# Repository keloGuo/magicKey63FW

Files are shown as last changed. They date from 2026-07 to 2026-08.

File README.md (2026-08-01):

# MagicKey63

<p align="right">
  English |
  <a href="README.zh-CN.md">中文</a>
</p>

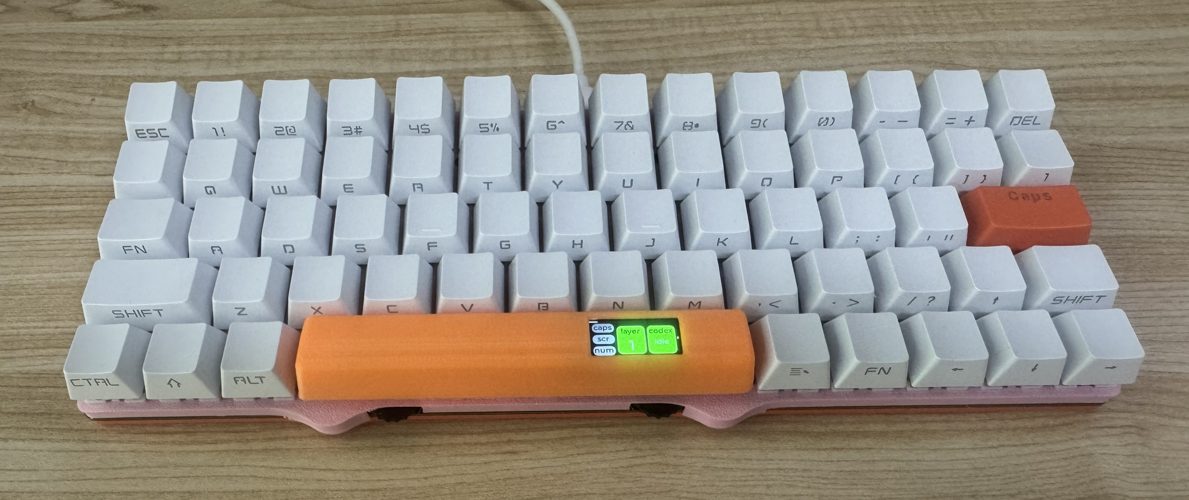
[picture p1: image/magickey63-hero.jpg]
MagicKey63 keyboard front view


MagicKey63 is an open-source RP2040 interactive hardware platform built into a compact mechanical keyboard. It works as a daily 63-key keyboard, but it is also designed for engineers, makers, and firmware hackers who want to modify and extend their desktop tools.

The project includes RP2040 firmware, USB HID/RNDIS, a browser-based web configuration UI, LittleFS storage, an LVGL onboard screen UI, WS2812 lighting, macro recording/playback, switch bounce diagnostics, hardware files, and mechanical design files.

### Features

- Compact 63-key layout with arrow keys and practical editing keys.
- RP2040 firmware with matrix scanning, USB HID, USB networking, and device-side HTTP APIs.
- Self-hosted web configuration page for keymap editing, macro management, resource upload, and version display.
- The web settings page can be updated independently without reflashing the full firmware.
- LVGL onboard UI with status, layer, lighting, network, and bootloader pages.
- Hidden dual clickable encoders for layer switching, volume, menu control, or custom workflows.
- Device-side macro recording, storage, and playback without host-side macro software.
- PIO/DMA-based key scanning and WS2812 driving to reduce real-time CPU load.
- Switch bounce diagnostics for validating switches, debounce behavior, and scan timing.
- Firmware, web UI, hardware files, and mechanical files are open-sourced under separate licenses.

### Build

Build from the repository root. A local Raspberry Pi Pico SDK checkout is required:

```sh
export PICO_SDK_PATH=/path/to/pico-sdk
cmake -S . -B build
cmake --build build
```

The generated UF2 is available at:

```text
build/firmware.uf2
```

For release and debug builds, use the project script:

```sh
tool/build_firmware.sh --release --incremental -j 8
tool/build_firmware.sh --release --clean -j 8
tool/build_firmware.sh --debug --incremental -j 8
```

Local checks:

```sh
tool/check_ci.sh
```

### Flash

When the device is connected to a Windows host through WSL2, use:

```sh
WINDOWS_DRIVE='E:\' TIMEOUT_SECONDS=120 ./tool/flash_uf2_wsl.sh
```

If the device IP has been changed, provide the matching bootloader URL:

```sh
BOOTLOADER_URL=http://172.23.63.1/api/rebootToUf2 ./tool/flash_uf2_wsl.sh
```

You can also enter UF2 mode manually and copy `build/firmware.uf2` to the `RPI-RP2` volume.

### Web Configuration

Default USB network address:

```text
http://10.63.27.1:80
```

The device can switch to alternate IP presets or a custom IP. Tool scripts accept `DEVICE_URL` and `BOOTLOADER_URL`:

```sh
DEVICE_URL=http://172.23.63.1:80 python3 tool/upload_html.py
BOOTLOADER_URL=http://172.23.63.1/api/rebootToUf2 ./tool/flash_uf2_wsl.sh
```

After editing `web/webServer/index.html`, `index.css`, or `main.js`, regenerate the tracked single-file page:

```sh
python3 tool/build_single_html.py
git diff --exit-code -- web/webServer/out/index.html
```

### License Notes

Different parts of this repository use different licenses. See `LICENSE` and `THIRD_PARTY_LICENSES.md`.

- Firmware, web UI, and development tools: GPL-2.0-only.
- Hardware electronics design files: CERN-OHL-S-2.0.
- Case and mechanical 3D files: CC-BY-SA-4.0.
- Mongoose is licensed as `GPL-2.0-only or commercial`. This firmware project uses the GPL-2.0-only option. Closed-source or non-GPL commercial redistribution requires separate Mongoose commercial licensing.
- LVGL, littlefs, cJSON, TinyUSB, and Pico SDK components keep their own license notices.

### VID/PID Status

The USB VID/PID has been updated to the Raspberry Pi provided assignment: `0x2E8A:0x113A`. The assignment source is documented in `firmware/usb/usb_descriptors.c`, and the firmware no longer uses TinyUSB demo IDs or a temporary development PID.

Before release, run:

```sh
tool/check_ci.sh --strict-release
```

## Repository Layout

- `firmware/`: RP2040 Pico SDK firmware source code and firmware-side third
  party libraries.
- `web/`: Web settings UI source files and generated single-file output.
- `tool/`: Development, upload, flashing, packaging, and Codex status sync
  scripts.
- `case_3d/`: Keyboard enclosure and mechanical structure 3D files.
- `hardware/`: Schematics and hardware manufacturing source/export files.
- `tool/dist/`: Generated tool package artifacts.
- `build/`: Local CMake build output.

## Release Artifacts

`tool/build_firmware.sh` records the Pico SDK path and git commit, runs
`arm-none-eabi-size`, and copies release artifacts to:

```text
build/release/<BuildType>/firmware.uf2
build/release/<BuildType>/firmware.elf
build/release/<BuildType>/firmware.map
build/release/<BuildType>/firmware.size.txt
build/release/<BuildType>/build-info.txt
```

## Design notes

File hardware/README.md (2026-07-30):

# MagicKey63 Hardware

This directory contains the electronics design files for the current
MagicKey63 prototype revision.

## Available Files

- `ProPrj_magicKey.epro2` - Editable JLCEDA Pro project archive containing
  the schematic and PCB layout sources for the current prototype.
- `SCH_magicKeySCH.pdf` - Main keyboard schematic, including the RP2040,
  key matrix, RGB LEDs, power circuitry, encoders, and peripheral interfaces.
- `SCH_magicKeyLcd.pdf` - Display interconnect board schematic.
- `SCH_magicKeyUSB.pdf` - USB-C connector board schematic.
- `BOM_magicKey.xlsx` - Preliminary electronics BOM covering the main,
  display, and USB-C boards.

The `.epro2` archive can be imported into the free JLCEDA Pro editor.

## Manufacturing Status

The editable PCB sources, schematic PDFs, and preliminary electronics BOM
are available now. Verified Gerber and drill files, pick-and-place data,
assembly drawings, and the production-qualified BOM will be added after the
pilot revision is frozen.

Keyboard enclosure and mechanical 3D files are stored separately in
`case_3d/`.

## License

Hardware electronics design files in this directory are licensed under
CERN-OHL-S-2.0. See `hardware/LICENSE`.

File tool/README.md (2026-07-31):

# Tools

This directory contains development and device utility scripts.

## Firmware And Web Tools

- `build_firmware.sh`: Configures and builds firmware release/debug artifacts,
  records Pico SDK version information, runs `arm-none-eabi-size`, and copies
  UF2/ELF/map outputs under `build/release/<BuildType>/`.
- `check_ci.sh`: Runs the local CI-style checks: whitespace, generated web page,
  old IP hard-coding, VID/PID release notes, CMake configure, firmware build,
  and firmware size output.
- `build_single_html.py`: Builds the web settings UI source files into one
  compact `web/webServer/out/index.html` file. Re-run it after changing
  `web/webServer/index.html`, `web/webServer/index.css`, or
  `web/webServer/main.js`.
- `pack_upload_page.py`: Converts `web/webUpdte/index.html` into generated C
  array source/header files for the firmware embedded upload page. This packed
  page is the recovery UI served from `/update`. CMake runs this automatically
  when the upload page changes.
- `upload_html.py`: Uploads the generated settings page to the device LittleFS
  through the HTTP update API. The device URL can be supplied with
  `--device-url` or the `DEVICE_URL` environment variable.
- `flash_uf2_wsl.sh`: Reboots the RP2040 into UF2 mode and copies
  `build/firmware.uf2` to the Windows `RPI-RP2` drive from WSL2.

Common commands:

```sh
tool/check_ci.sh
tool/build_firmware.sh --release --incremental -j 8
python3 tool/build_single_html.py
git diff --exit-code -- web/webServer/out/index.html
python3 tool/upload_html.py web/webServer/out/index.html
WINDOWS_DRIVE='E:\' TIMEOUT_SECONDS=120 ./tool/flash_uf2_wsl.sh
```

## Codex Status Sync

- `codex_app_server_hook.py`: Reads Codex App Server state and usage data, then
  posts status updates to the keyboard.
- `codex_status.sh`: Manually posts one status value to the device.
- `device_discover.sh`: Finds the keyboard HTTP URL for Codex status sync.
- `ucodex`: Starts Codex with an App Server and a status watcher so keyboard
  LEDs and UI can reflect Codex working state.
- `build_ucodex_deb.sh`: Packages `ucodex` and the status hook as a Debian
  package under `dist/`.

Common commands:

```sh
./tool/codex_status.sh active
./tool/ucodex
./tool/build_ucodex_deb.sh
```

## Environment

Useful variables:

- `DEVICE_URL`: Device HTTP base URL. If unset, Codex status tools discover the
  keyboard and cache the result in `~/.ucodex/device_url`.
- `DEVICE_URL_CANDIDATES`: Space-separated URLs scanned by
  `device_discover.sh`. Default includes `10.63.27.1`, `10.63.27.2`, and
  `192.168.3.1`.
- `BOOTLOADER_URL`: Device bootloader API URL used by flashing scripts. Default
  is `http://10.63.27.1/api/rebootToUf2`.
- `WINDOWS_DRIVE`: Windows drive letter for the mounted `RPI-RP2` volume, for
  example `E:\`.
- `TIMEOUT_SECONDS`: Flash script wait timeout.
- `UF2_PATH`: Override the firmware UF2 path used by `flash_uf2_wsl.sh`.
- `BUILD_TYPE`: Firmware build type used by `build_firmware.sh`.
- `JOBS`: Parallel build jobs used by `build_firmware.sh`.
- `SIZE_TOOL`: Size tool used by `build_firmware.sh`. Default is
  `arm-none-eabi-size`.
- `FORBIDDEN_IP_PATTERN`: Extended regexp used by `check_ci.sh` to detect old
  hard-coded device IPs. Default is `192\.168\.3\.1`.
- `STRICT_RELEASE`: Set to `1` to make `check_ci.sh` fail on release blockers
  such as temporary VID/PID notes.
- `CODEX_BIN`: Codex executable used by `ucodex`.

Run scripts from the repository root unless a script documents otherwise.

If the keyboard network page is set to another IP preset or a custom IP, pass
the matching URL explicitly:

```sh
DEVICE_URL=http://172.23.63.1:80 python3 tool/upload_html.py
BOOTLOADER_URL=http://172.23.63.1/api/rebootToUf2 ./tool/flash_uf2_wsl.sh
```

## Web Update Recovery

The main settings page is uploaded to LittleFS as `index.html`. The smaller
`web/webUpdte/index.html` page is embedded in the firmware and is served from
`/update`, so it remains available even when the LittleFS settings page needs to
be replaced.

Recovery workflow:

```sh
python3 tool/build_single_html.py
DEVICE_URL=http://<device-ip>:80 python3 tool/upload_html.py web/webServer/out/index.html
```

If the browser cannot load the main page, open `http://<device-ip>/update` and
use the packed update page to restore the LittleFS page.

## License

Development and device utility scripts in this directory are licensed under
GPL-2.0-only. See `tool/LICENSE`.

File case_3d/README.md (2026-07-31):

# Case 3D Files

This directory stores keyboard enclosure and mechanical structure files.

## Editable Source Files

- `top-cover-positioning-plate.step`: Top cover and positioning plate.
- `keyboard-bottom-cover-v3.1.8.step`: Keyboard bottom cover.
- `spacebar-keycap.step`: Spacebar keycap.

## Preview Mesh Files

These STL files are exported for lightweight web preview and 3D model viewing.
Use the STEP files above as the editable mechanical source.

- `positioning-plate.stl`: Positioning plate preview mesh.
- `keyboard-bottom-cover-v3.1.8.stl`: Keyboard bottom cover preview mesh.
- `spacebar-keycap.stl`: Spacebar keycap preview mesh.

## File Types

Preferred source formats:

- `STEP` / `STP`: Mechanical source exchange format.
- `3MF`: 3D printing project format.
- `STL`: 3D printing mesh export.
- `DXF`: 2D plate or outline export.

When adding generated exports, keep the editable source file as well.

## License

Case and mechanical 3D files in this directory are licensed under
CC-BY-SA-4.0. See `case_3d/LICENSE`.

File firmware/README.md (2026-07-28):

# Firmware

This directory contains the RP2040 Pico SDK firmware source code for
MagicKey63.

## Build Entry

Build from the repository root, not from this directory:

```sh
cmake -S . -B build
cmake --build build
```

The root CMake file imports the Pico SDK and then adds this directory with
`add_subdirectory(firmware)`.

Release and debug builds are wrapped by `tool/build_firmware.sh`:

```sh
tool/build_firmware.sh --release --incremental -j 8
tool/build_firmware.sh --release --clean -j 8
tool/build_firmware.sh --debug --incremental -j 8
```

The script supports clean and incremental builds, passes
`CMAKE_BUILD_TYPE=Release` or `Debug`, runs the build in parallel, records the
Pico SDK git commit, runs `arm-none-eabi-size`, and copies the UF2, ELF, and map
file into `build/release/<BuildType>/`.

## Directory Layout

- `main.c`: Firmware entry point and system startup flow.
- `magic63_config.h`: Shared hardware and firmware configuration.
- `keyboardScan/`: PIO/DMA keyboard matrix scanning and bounce diagnostic
  support.
- `PIO/`: Standalone PIO programs used by firmware features.
- `usb/`: TinyUSB HID descriptors, reports, and USB device logic.
- `rndis/`: RNDIS network interface, HTTP server, and web API handlers.
- `dataSave/`: Persistent settings storage.
- `macroRecorder/`: Macro recording, storage, and playback support.
- `UI/`: LVGL screen pages, page switching, and UI data handling.
- `lvglPort/`: LVGL display port for the ST7735 screen.
- `st7735/`: ST7735 display driver.
- `ws2812/`: WS2812 LED driver and PIO program.
- `keymap/`: Key value and keymap related logic.
- `apm/`: APM counting.
- `boot/`: Reboot and UF2 bootloader entry helpers.
- `debug/`: Optional debug output and status logging helpers.
- `scratch/`: Shared scratch memory support.
- `lib/`: Firmware-side third party libraries, including LVGL, LittleFS, and
  cJSON.
- `zCmakeFile/`: Pico SDK import helper.

## Output

CMake generates the firmware executable and UF2 under `build/`. A compatibility
copy is kept at:

```text
build/firmware.uf2
```

This keeps existing flashing scripts working after the firmware source was moved
under `firmware/`.

## USB Device Identity

RP2040 does not provide a built-in unique chip ID. MagicKey63 uses the external
QSPI flash unique ID through Pico SDK `pico_unique_id`.

- USB string descriptor serial: the full 8-byte flash unique ID encoded as 16
  uppercase hexadecimal characters.
- RNDIS MAC address: generated from the same flash unique ID before USB
  initialization. The first byte is fixed to `0x02`, which makes the address a
  locally administered unicast MAC address. The remaining five bytes are mixed
  from the flash unique ID bytes.
- TinyUSB RNDIS reports and the Mongoose TCP/IP interface use the same generated
  MAC address.
- Device IP address is configurable. When multiple keyboards are connected to
  the same host at the same time, configure each keyboard to use a different IP
  preset or custom IP to avoid HTTP/RNDIS address conflicts.

After changing VID, PID, serial, MAC, or IP settings, verify enumeration on the
target host OS. Windows, macOS, and Linux may cache USB and network interface
state differently.

## Versioning

- Firmware version string: set by `MAGIC63_FIRMWARE_VERSION` in
  `firmware/CMakeLists.txt`. The default development value is `0.1.0-dev`.
- USB `bcdDevice`: defined as `MAGIC63_USB_BCD_DEVICE` in
  `firmware/magic63_version.h`. It uses packed BCD `0xMMmm`, where `MM` is the
  public major version and `mm` is the public minor version. Development builds
  before the first public release use `0x0100`.
- Persistent configuration schema: defined as `MAGIC63_CONFIG_VERSION` in
  `firmware/magic63_version.h`.
- Settings web page version: defined by `MAGIC63_SETTINGS_PAGE_VERSION` in
  `web/webServer/main.js`.
- Packed upload page version: defined by `MAGIC63_UPLOAD_PAGE_VERSION` in
  `web/webUpdte/index.html` and embedded into firmware by
  `tool/pack_upload_page.py`.

The `/api/versionInfo` endpoint exposes the firmware version, configuration
schema version, USB `bcdDevice`, and packed upload page version. The settings
web page combines that response with its own page version.

When the main persistent configuration structure changes, increment
`MAGIC63_CONFIG_VERSION`. The current migration policy is conservative: if the
stored structure size or schema version does not match, firmware restores the
main configuration and keymap to defaults. Network configuration is stored
separately as `netConfigData` and is validated by its own magic value.

## License

Firmware source code in this directory is licensed under GPL-2.0-only. See
`firmware/LICENSE`.

Third party libraries under `firmware/lib/` and other imported files keep their
own license notices.

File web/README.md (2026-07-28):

# Web

This directory contains the embedded web settings UI used by the device HTTP
server.

## Layout

- `webServer/`: Main settings UI source files.
  - `index.html`: HTML structure for the settings page.
  - `index.css`: Page styles.
  - `main.js`: Keyboard layout, key binding, macro editing, upload, and device
    API logic.
  - `out/index.html`: Generated single-file page uploaded to LittleFS on the
    device.
- `webUpdte/`: Minimal update/upload page kept separately from the main
  settings UI.

## Build Single HTML

The device serves a single compressed HTML file from LittleFS. After editing
`webServer/index.html`, `webServer/index.css`, or `webServer/main.js`, rebuild
the generated page from the repository root:

```sh
python3 tool/build_single_html.py
```

The output is:

```text
web/webServer/out/index.html
```

Do not edit `webServer/out/index.html` directly. It is generated output, but it
is intentionally tracked so a release can include and review the exact page that
will be uploaded to the device.

To check whether the tracked output matches the current source files, rebuild
the page and then inspect the diff:

```sh
python3 tool/build_single_html.py
git diff -- web/webServer/out/index.html
```

For CI or release checks, use `git diff --exit-code -- web/webServer/out/index.html`
after rebuilding.

## Upload To Device

After rebuilding the single HTML file, upload it to the device:

```sh
python3 tool/upload_html.py web/webServer/out/index.html
```

The default device URL is `http://10.63.27.1`. Override it with
`--device-url` or `DEVICE_URL` when the keyboard network page is set to another
IP preset or a custom IP.

Examples:

```sh
python3 tool/upload_html.py --device-url http://172.23.63.1:80
DEVICE_URL=http://172.23.63.1:80 python3 tool/upload_html.py
```

## LittleFS Page And Packed Update Page

The firmware has two web page paths:

- Main settings page: generated from `webServer/index.html`,
  `webServer/index.css`, and `webServer/main.js`, then uploaded to LittleFS as
  `/index.html`.
- Packed update page: generated from `webUpdte/index.html` and embedded into
  the firmware image as `/web_root/update/index.html`.

The normal configuration UI should come from LittleFS. The packed update page is
kept in firmware as a recovery path and can be opened with:

```text
http://<device-ip>/update
```

If the LittleFS page is missing, damaged, or a page upload fails before the main
UI is usable again, use the packed update page or rerun `tool/upload_html.py` to
upload a fresh `web/webServer/out/index.html`.

## Notes

- Keep source edits in `index.html`, `index.css`, and `main.js`.
- The embedded web page uses relative `/api/...` paths, so it follows the
  current device IP instead of a hard-coded address.
- The firmware-side HTTP API handlers are under `firmware/rndis/`.

## License

Web UI source files and generated embedded page output are licensed under
GPL-2.0-only. See `web/LICENSE`.

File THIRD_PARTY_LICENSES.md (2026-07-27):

# Third Party Licenses

This document summarizes third party software used by MagicKey63. It is a
release checklist and redistribution notice companion for source packages,
firmware binaries, and tool packages.

This summary does not replace the original license notices. If a third party
file contains its own copyright header, SPDX identifier, or license text, that
notice applies to that file and must be preserved.

## Summary

| Component | Location | License | Notes |
| --- | --- | --- | --- |
| Mongoose | `firmware/rndis/mongoose.c`, `firmware/rndis/mongoose.h` | GPL-2.0-only or commercial | Bundled in firmware source. The GPL-2.0-only option is used for this GPL-2.0-only firmware project. A commercial Mongoose license is needed for non-GPL proprietary redistribution. |
| LVGL | `firmware/lib/lvgl/` | MIT | Bundled in firmware source. Original license text is kept at `firmware/lib/lvgl/LICENCE.txt`. |
| littlefs | `firmware/lib/littlefs/` | BSD-3-Clause | Bundled in firmware source. Source files keep SPDX headers. |
| cJSON | `firmware/lib/cJson/` | MIT | Bundled in firmware source. Source and header files keep the MIT license header. |
| TinyUSB | Pico SDK dependency, usually `${PICO_SDK_PATH}/lib/tinyusb/` | MIT | Not vendored in this repository. Used through the Raspberry Pi Pico SDK at build time. |
| Raspberry Pi Pico SDK | External build dependency, `${PICO_SDK_PATH}` | BSD-3-Clause | Not vendored in this repository. Firmware builds link Pico SDK libraries and headers. |

## Bundled Components

### Mongoose

Files:

- `firmware/rndis/mongoose.c`
- `firmware/rndis/mongoose.h`

License:

- `GPL-2.0-only or commercial`

The bundled Mongoose header states that Mongoose is dual licensed. This project
uses the GPL-2.0-only option, matching the firmware license. Keep the original
Mongoose copyright and license header in redistributed source.

If MagicKey63 firmware is redistributed outside the GPL-2.0-only terms, review
Mongoose's commercial licensing requirements first.

### LVGL

Directory:

- `firmware/lib/lvgl/`

License:

- `MIT`

Original license file:

- `firmware/lib/lvgl/LICENCE.txt`

Keep LVGL's license file and any file-level notices when redistributing source.

### littlefs

Directory:

- `firmware/lib/littlefs/`

License:

- `BSD-3-Clause`

The littlefs source files include SPDX license headers such as:

```text
SPDX-License-Identifier: BSD-3-Clause
```

Keep these headers when redistributing source.

### cJSON

Directory:

- `firmware/lib/cJson/`

License:

- `MIT`

The cJSON source and header files include the MIT license text. Keep those
headers when redistributing source.

## External Build Dependencies

### TinyUSB

Typical local SDK path:

- `${PICO_SDK_PATH}/lib/tinyusb/`

License:

- `MIT`

TinyUSB is used through the Pico SDK build. It is not vendored in this
repository. When distributing binary firmware, include TinyUSB's MIT license
notice in the release license bundle.

### Raspberry Pi Pico SDK

Typical local SDK path:

- `${PICO_SDK_PATH}`

License:

- `BSD-3-Clause`

The Pico SDK is an external build dependency and is not vendored in this
repository. When distributing binary firmware, include the Pico SDK BSD-3-Clause
license notice in the release license bundle.

The Pico SDK also contains optional third party submodules, such as BTstack,
cyw43-driver, lwIP, mbedTLS, and TinyUSB. MagicKey63 should include notices for
the Pico SDK components actually linked into a release build.

## Redistribution Checklist

For source releases:

- [ ] Include this `THIRD_PARTY_LICENSES.md` file.
- [ ] Keep bundled third party source directories with their original file
      headers and license notices.
- [ ] Keep `firmware/lib/lvgl/LICENCE.txt`.
- [ ] Keep cJSON and littlefs source headers intact.
- [ ] Keep Mongoose copyright and license headers intact.

For firmware binary releases:

- [ ] Include this `THIRD_PARTY_LICENSES.md` file.
- [ ] Include the repository license summary in `LICENSE`.
- [ ] Include Mongoose GPL-2.0-only/commercial notice.
- [ ] Include LVGL MIT notice.
- [ ] Include littlefs BSD-3-Clause notice.
- [ ] Include cJSON MIT notice.
- [ ] Include TinyUSB MIT notice.
- [ ] Include Pico SDK BSD-3-Clause notice.
- [ ] Record the Pico SDK version or commit used for the build.

For tool package releases:

- [ ] Include `tool/LICENSE`.
- [ ] Include this third party license summary if the package contains firmware,
      generated web assets, or bundled third party source.

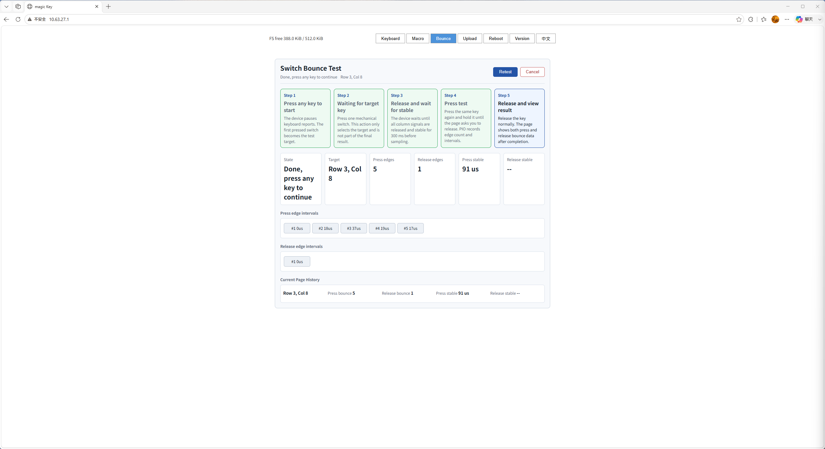
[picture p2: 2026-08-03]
image/web按键抖动检测页.png

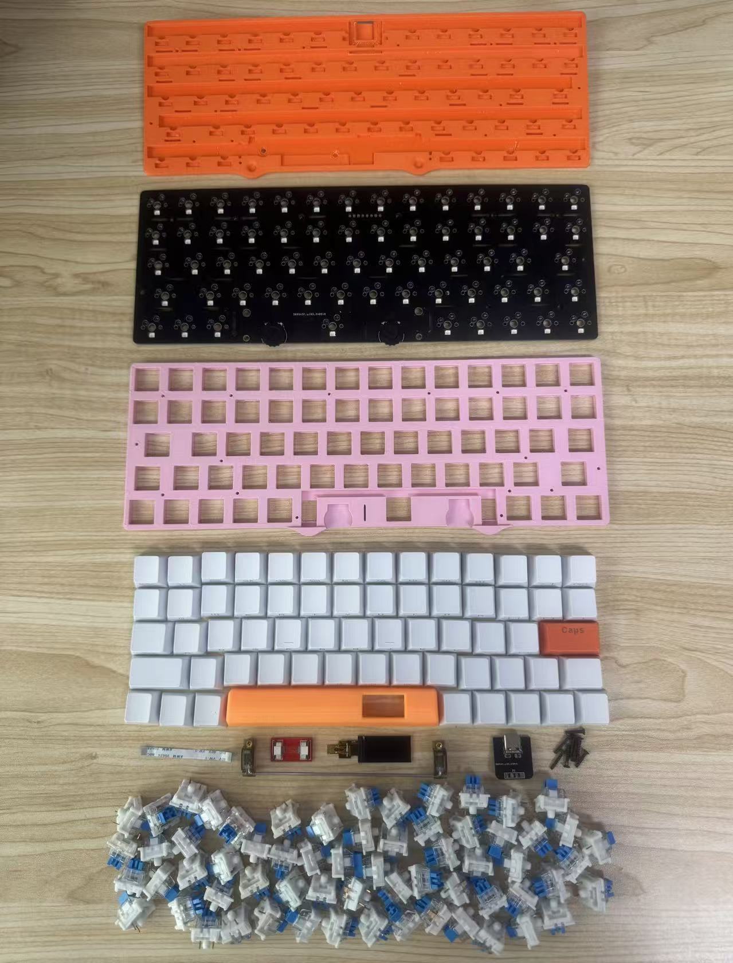
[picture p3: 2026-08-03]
image/零件图.jpg

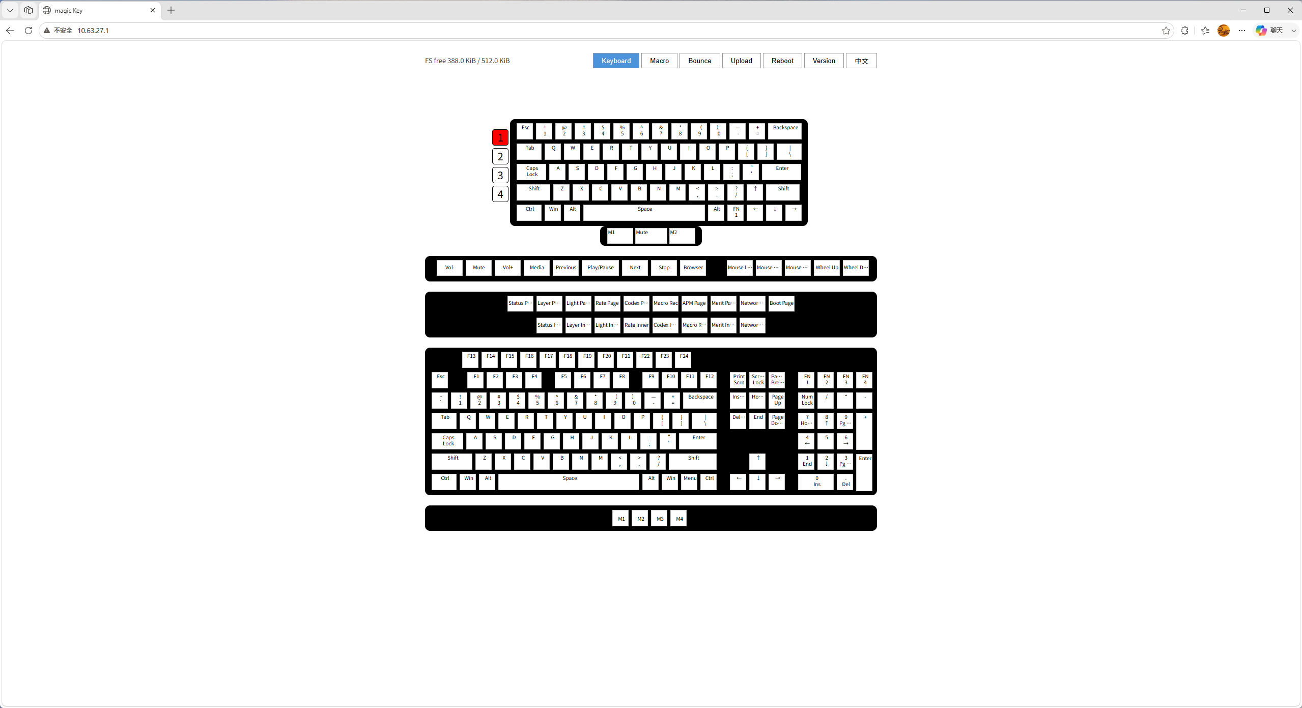
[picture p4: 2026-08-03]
image/web主页.png

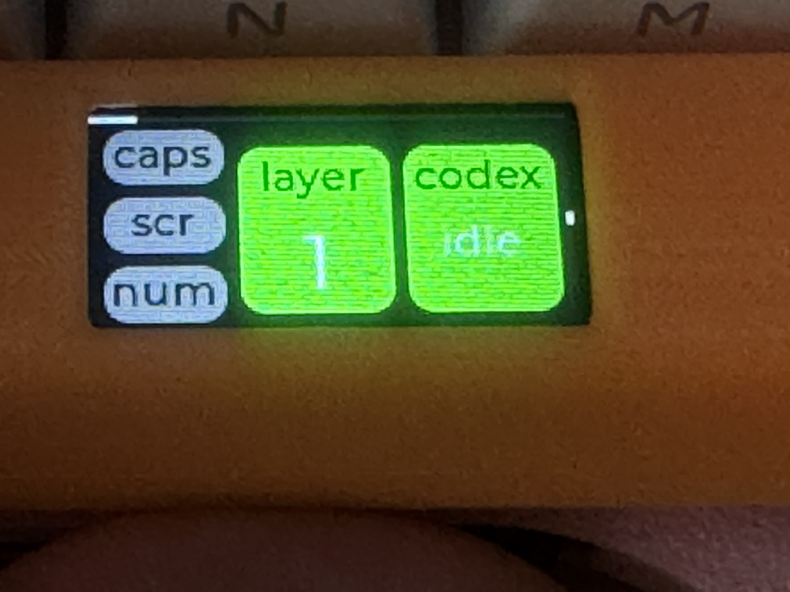
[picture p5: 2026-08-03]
image/屏幕状态页.jpg

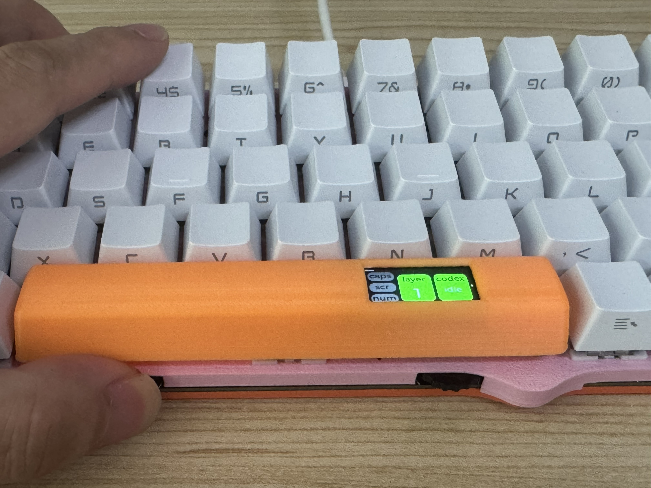
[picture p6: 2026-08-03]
image/操作编码器.jpg

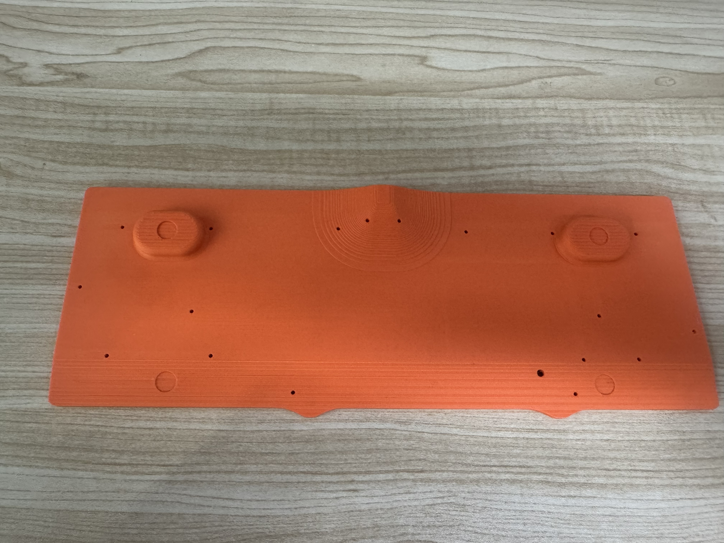
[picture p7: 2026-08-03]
image/底壳背面.jpg

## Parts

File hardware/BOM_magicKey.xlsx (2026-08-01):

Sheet: BOM_magicKeySCH_magicKeySCH_202
No. | Quantity | Comment | Designator | Footprint | Value | Manufacturer Part | Manufacturer | Supplier Part | Supplier
1 | 63 | KEY-PB8 | A1,A2,A3,A4,A5,A6,A7,A8,A9,A10,A11,A12,A13,A14,A15,A16,A17,A18,A19,A20,A21,A22,A23,A24,A25,A26,A27,A28,A29,A30,A31,A32,A33,A34,A35,A36,A37,A38,A39,A40,A41,A42,A43,A44,A45,A46,A47,A48,A49,A50,A51,A52,A53,A54,A55,A56,A57,A58,A59,A60,A61,A62,A63 | KEY |  | K2-1107ST-A4SW-06 |  | C118141 | LCSC
2 | 9 | 100nF | C1,C5,C8,C9,C10,C11,C14,C15,C18 | C0402
3 | 2 | 100nF | C6,C20 | C0402
4 | 3 | 100nF | C7,C12,C13 | C0402
5 | 30 | BAT54C KL3 | D1,D2,D3,D4,D5,D6,D7,D8,D9,D10,D11,D12,D13,D14,D15,D16,D17,D18,D19,D20,D22,D23,D24,D25,D26,D27,D28,D29,D31,D32 | SOT-3 |  | BAT54C KL3 | CBI(创基) | C2828464 | LCSC
6 | 9 | 1N5819WS S4_C2927280 | D21,D30,D33,D34,D35,D36,D37,D38,D50 | SOD-123W_L2.8-W1.8-LS3.7-RD |  | 1N5819WS S4 | JSMSEMI(杰盛微) | C2927280 | LCSC
7 | 1 | 1206L005/60WR | F1 | 0805 |  | 1206L005/60WR | Littelfuse(美国力特) | C315892 | LCSC
8 | 1 | 0.5K-1.5-8PWB | FPC1 | FPC-SMD_8P-P0.50_HDGC_0.5K-1.5-8PWB |  | 0.5K-1.5-8PWB | HDGC(华德共创) | C2919555 | LCSC
11 | 1 | 2301 | Q1 | SOT-23-3_L2.9-W1.3-P1.90-LS2.4-BR |  | 2301 | FM | C86773 | LCSC
12 | 2 | 1K | R1,R7 | R0402 | 1K
13 | 1 | 200R | R2 | R0402 | 200R
14 | 3 | 27 | R3,R6,R12 | R0402 | 27
15 | 1 | 2M | R13 | R0402
16 | 1 | 1K | R14 | R0402
17 | 63 | Header 2X2 | RB1,RB2,RB3,RB4,RB5,RB6,RB7,RB8,RB9,RB10,RB11,RB12,RB13,RB14,RB15,RB16,RB17,RB18,RB19,RB20,RB21,RB22,RB23,RB24,RB25,RB26,RB27,RB28,RB29,RB30,RB31,RB32,RB33,RB34,RB35,RB36,RB37,RB38,RB39,RB40,RB41,RB42,RB43,RB44,RB45,RB46,RB47,RB48,RB49,RB50,RB51,RB52,RB53,RB54,RB55,RB56,RB57,RB58,RB59,RB60,RB61,RB62,RB63 | SOP-4
18 | 1 | TS-1076S-A15B3 | SW1 | SW-SMD_4P-L5.2-W5.2-P3.70-LS6.4 |  | TS-1076S-A15B3 | Yuandi(元迪) | C493017 | LCSC
19 | 1 | W25Q16FWUXIE | U1 | USON8_L2.0-W3.0-P0.50-BL-EP |  | W25Q16FWUXIE | WINBOND(华邦) | C401672 | LCSC
20 | 1 | RP2040 | U3 | LQFN-56_L7.0-W7.0-P0.4-EP
21 | 2 | SIQ-02FVS3 | U4,U5 | SW-SMD_SIQ-02FVS3_1 |  | SIQ-02FVS3 | MITSUMI(美上美) | C2925423 | LCSC
22 | 1 | RT9013-33GB | U6 | SOT-23-5_L3.0-W1.7-P0.95-LS2.8-BL |  | RT9013-33GB | RICHTEK(立锜) | C47773 | LCSC
23 | 1 | XTAL | X1 | SOP-3

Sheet: BOM_magicKeyLcd_magicKeyLcd_202
No. | Quantity | Comment | Designator | Footprint | Value | Manufacturer Part | Manufacturer | Supplier Part | Supplier
1 | 2 | 0.5K-1.5-8PWB | FPC1,FPC2 | FPC-SMD_AFC07-S08ECC-00 |  | 0.5K-1.5-8PWB | HDGC(华德共创) | C2919555 | LCSC

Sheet: BOM_magciKeyUSB_magciKeyUSB_202
No. | Quantity | Comment | Designator | Footprint | Value | Manufacturer Part | Manufacturer | Supplier Part | Supplier
1 | NC | Header 4 | P1 | HDR1X4
2 | 2 | 5.1kΩ | R1,R2 | 0603 | 5.1kΩ | 0603WAF5101T5E | UNI-ROYAL(厚声) | C23186 | LCSC
3 | 1 | TYPEC-304-ACP16 | USB1 | SOP-8 - duplicate |  | TYPEC-304-ACP16 | XUNPU(讯普) | C2982555 | LCSC

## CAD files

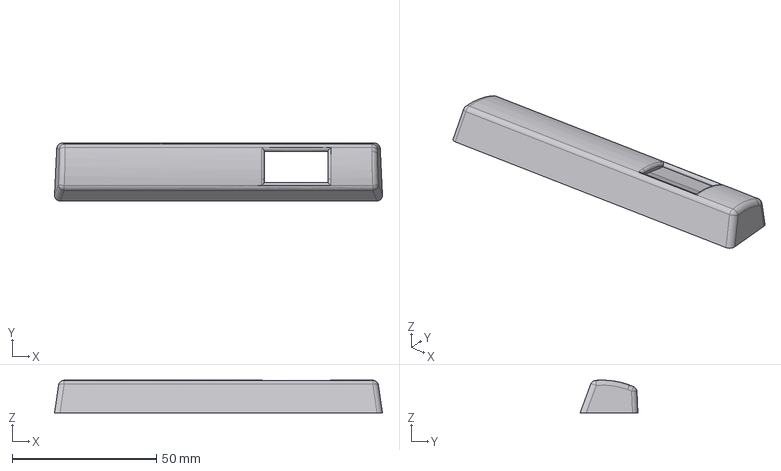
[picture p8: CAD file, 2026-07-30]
case_3d/spacebar-keycap.step
113.9 x 20.1 x 11.4 mm

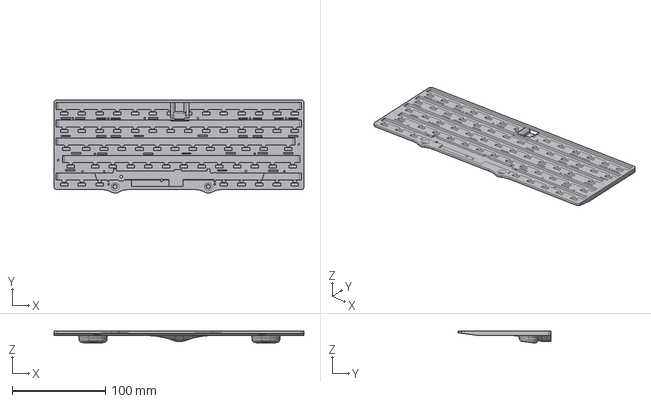
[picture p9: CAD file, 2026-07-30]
case_3d/keyboard-bottom-cover-v3.1.8.step
268.4 x 100.1 x 13.1 mm

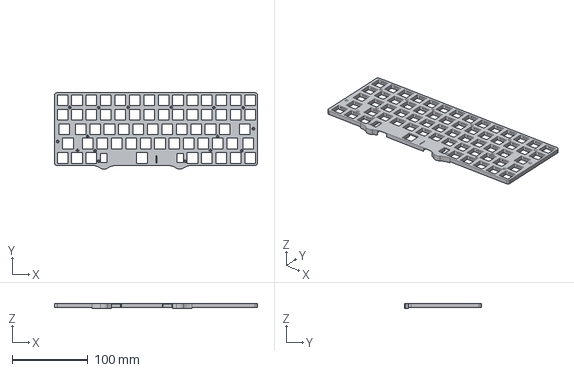
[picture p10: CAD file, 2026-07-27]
case_3d/top-cover-positioning-plate.step
268.0 x 101.0 x 6.60 mm

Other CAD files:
case_3d/spacebar-keycap.stl

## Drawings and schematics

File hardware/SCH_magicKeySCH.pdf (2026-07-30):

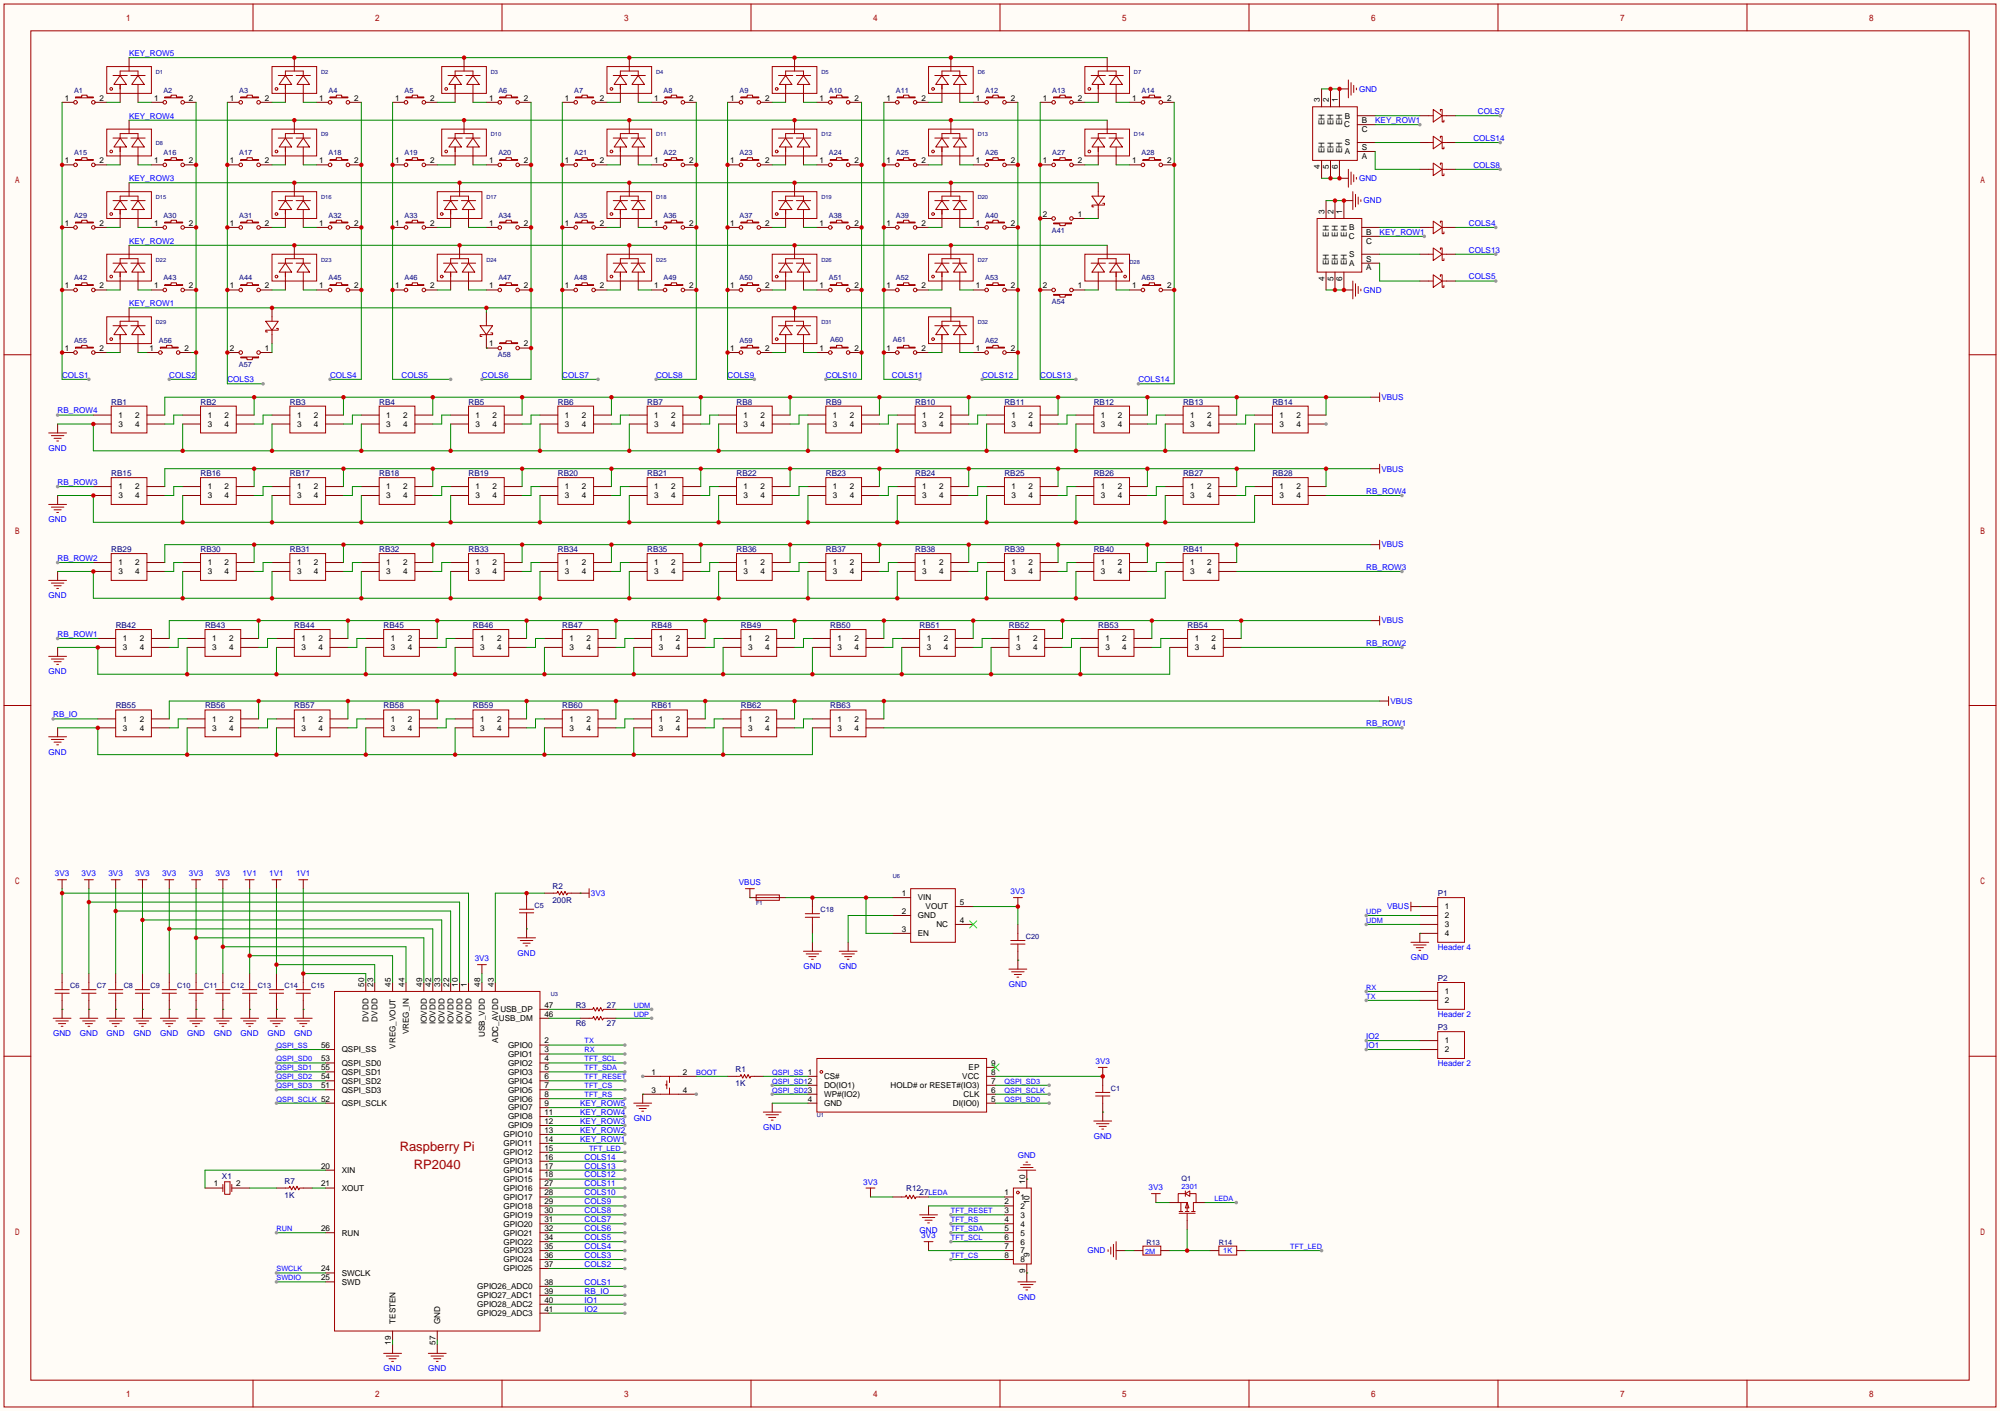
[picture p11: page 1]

GND GND GND

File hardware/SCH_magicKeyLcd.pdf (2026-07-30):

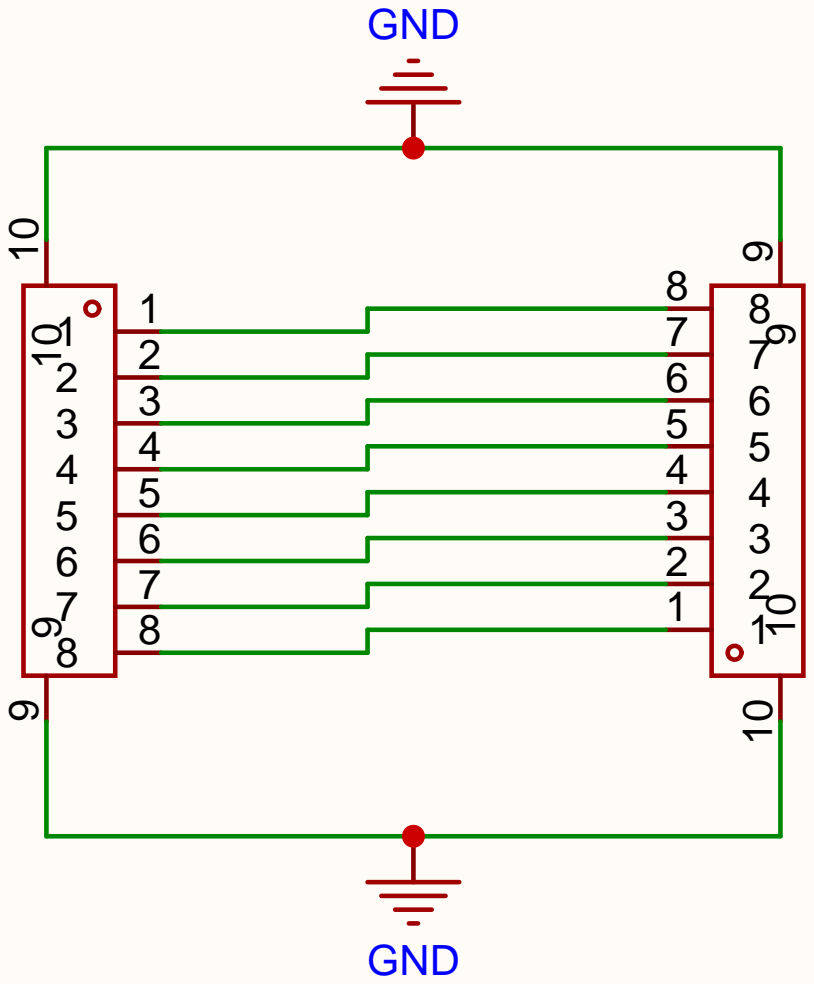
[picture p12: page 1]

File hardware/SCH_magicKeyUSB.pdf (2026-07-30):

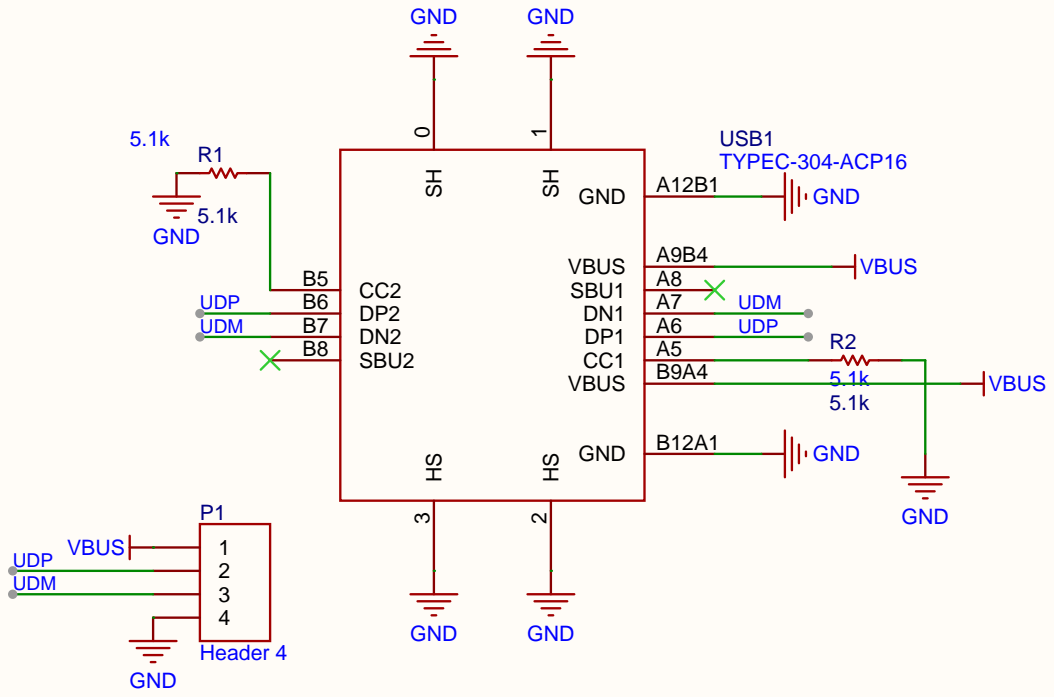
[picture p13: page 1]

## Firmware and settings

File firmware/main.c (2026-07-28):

// Copyright (c) 2022 Cesanta Software Limited
// All rights reserved

#include "pico/stdlib.h"
#include "pico/multicore.h"
#include "pico/bootrom.h"
#include "hardware/clocks.h"
#include "tusb.h"
#include "lvgl.h"
#include "lv_port_disp.h"
#include <malloc.h>

unsigned char keyboardReportInit(void);
unsigned char rndisInit(void);
unsigned char mgLoops(void);
void webBounceDiagPollTimeout(void);
unsigned char keyboardScanInit(void);
unsigned char st7735Int(void);
unsigned char uiDataUpdateInit(void);
unsigned char encoderTmierInit(void);
unsigned char dataSaveInit(void);
void core1_main(void);
void magic63UI(void);
unsigned char apmTimerInit(void);
unsigned char bootCleck(void);
unsigned char TestPrintf(void);
unsigned char encoderKeyCleckInit(void);
unsigned char keymap2HidReport(void);
unsigned char ws2812Init(void);
unsigned char tftBackLightCtrlInit(void);
unsigned char apmUpdataCleck(void);
void cdcDebugInit(void);
void debugStage(unsigned char core, unsigned int stage);
void debugHeartbeat(unsigned char core);
void debugMallinfoSample(unsigned int arena, unsigned int ordblks, unsigned int uordblks, unsigned int fordblks, unsigned int keepcost);
void debugEvent(const char *tag, int value);
void debugEventText(const char *tag, const char *text, int value);
void debugPrintf(const char* format, ...);
void scratchInit(void);
void keyBounceDiagPoll(void);
void keyBounceDiagCancel(void);
void keyboardReportSetPaused(unsigned char paused);
void magic63UsbSerialInit(void);
void magic63RndisMacInit(void);

void bounceDiagUiExitRequest(void)
{
	keyBounceDiagCancel();
	keyboardReportSetPaused(0);
}

#define PLL_SYS_KHZ (250 * 1000)
unsigned char sysClockInit(void)
{
	set_sys_clock_khz(PLL_SYS_KHZ, true);
	debugPrintf("clock_get_hz = %d \r\n", clock_get_hz(clk_sys));
	return 0;
}

unsigned char tftBackLightTest(void)
{
	gpio_init(12);
    gpio_set_dir(12, GPIO_OUT);
	gpio_put(12,1);
	return 0;
}
bool encoderProcess(repeating_timer_t *rt) ;
bool UIdataUpdate(repeating_timer_t *rt);
int main(void) 
{
	sysClockInit();
	stdio_init_all();
	cdcDebugInit();
	debugEventText("boot", "cdc_debug_init", 0);
	scratchInit();
	debugEventText("boot", "scratch_init", 0);
	multicore_lockout_victim_init();
	debugPrintf("cpu lvgl id %d \r\n", *((unsigned int *)(0xd0000000)));
	debugPrintf("clock_get_hz = %d \r\n", clock_get_hz(clk_sys));

	multicore_launch_core1(core1_main);
	debugEventText("boot", "core1_launch", 0);
	dataSaveInit();
	debugEventText("boot", "data_save", 0);
	keymap2HidReport();
	debugEventText("boot", "hid_desc", 0);
	st7735Int();
	debugEventText("boot", "lcd", 0);
	lv_init();
	lv_port_disp_init();
	debugEventText("boot", "lvgl", 0);
	
	magic63UI();
	debugEventText("boot", "ui", 0);

	magic63UsbSerialInit();
	debugEventText("boot", "usb_serial", 0);
	magic63RndisMacInit();
	debugEventText("boot", "rndis_mac", 0);
	tusb_init();
	debugEventText("boot", "tusb", 0);
	rndisInit();			
	debugEventText("boot", "rndis", 0);

	//encoderTmierInit();
	apmTimerInit();
	//uiDataUpdateInit();
	ws2812Init();
	debugEventText("boot", "ws2812", 0);

	tftBackLightCtrlInit();
	debugEventText("boot", "main_loop", 0);

    while(true) 
    {
		debugStage(0, 3);
		encoderProcess(NULL);
		UIdataUpdate(NULL);
		debugStage(0, 1);
		lv_task_handler(); 
		debugStage(0, 2);
		mgLoops();
		webBounceDiagPollTimeout();
		struct mallinfo mi = mallinfo();
		debugMallinfoSample((unsigned int)mi.arena, (unsigned int)mi.ordblks,
		                    (unsigned int)mi.uordblks, (unsigned int)mi.fordblks,
		                    (unsigned int)mi.keepcost);
		debugHeartbeat(0);
    }
  	return 0;
}
void cdc_task(void);
void core1_main(void)
{
	multicore_lockout_victim_init();
	debugEventText("core1", "start", 0);
	keyboardScanInit();
	debugEventText("core1", "scan_init", 0);
	sleep_ms(20);
	bootCleck();
	debugEventText("core1", "boot_check", 0);
	keyboardReportInit();
	debugEventText("core1", "hid_report", 0);
	encoderKeyCleckInit();
	debugEventText("core1", "encoder_key", 0);
	for (;;) 
	{
		debugStage(1, 10);
		tud_task();
		debugStage(1, 11);
		cdc_task();
		keyBounceDiagPoll();
		debugStage(1, 12);
		debugHeartbeat(1);
		// TestPrintf();
	}
}

struct repeating_timer backLightTimer;

bool backLightTimerHandle(repeating_timer_t *rt)
{
	gpio_init(12);
    gpio_set_dir(12, GPIO_OUT);
	gpio_put(12,1);
	return 1;

}
unsigned char tftBackLightCtrlInit(void)
{
	add_repeating_timer_ms(60000,backLightTimerHandle,0,&backLightTimer);
	return 0;
}
unsigned char tftBackLightCtrlTimerRestart(void)
{
	cancel_repeating_timer(&backLightTimer);
	gpio_init(12);
    gpio_set_dir(12, GPIO_OUT);
	gpio_put(12,0);
	add_repeating_timer_ms(60000,backLightTimerHandle,0,&backLightTimer);
	return 0;
}

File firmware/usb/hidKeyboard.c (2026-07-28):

#include <stdio.h>
#include <string.h>
#include <stdint.h>

#include "tusb.h"
#include "lfs.h"
#include "macroRecorder.h"

#define MACRO_MAGIC 0x4d414331u
#define MACRO_VERSION 1u
#define MACRO_MAX_ID 255u
#define MACRO_MAX_ACTIONS 64u
#define MACRO_FILE_PREFIX "macro_"
#define MACRO_TICK_MS 10u

typedef struct __attribute__((packed)) {
    uint32_t magic;
    uint16_t version;
    uint16_t action_count;
    uint16_t id;
    uint8_t mode;
    uint8_t reserved;
    uint32_t crc32;
} macro_entry_t;

typedef struct __attribute__((packed)) {
    uint8_t type;
    uint8_t value;
    uint16_t param;
} macro_action_t;

typedef struct __attribute__((packed)) {
    macro_entry_t header;
    macro_action_t actions[MACRO_MAX_ACTIONS];
} macro_data_t;

lfs_t *fsInit(void);
unsigned short getKeymapByXY(unsigned char x,unsigned char y);
void ws2812MacroPlayStart(void);
void ws2812MacroPlayStop(void);
void ws2812MacroPlayKey(unsigned char ledIndex, unsigned char pressed);
void debugStage(unsigned char core, unsigned int stage);
void debugEvent(const char *tag, int value);
void debugEventText(const char *tag, const char *text, int value);
void debugPrintf(const char* format, ...);
void pageJumpRequest(unsigned char index);
static unsigned char macroLedByXY(unsigned char x, unsigned char y);

static macro_data_t macroActive;
static unsigned char macroRunning = 0;
static unsigned char macroSourceId = 0;
static unsigned char macroSourceDown = 0;
static unsigned char macroIndex = 0;
static unsigned int macroDelayMs = 0;
static unsigned char macroKeyboardBits[16] = {0};
static unsigned int macroMediaBits = 0;
static unsigned int macroMouseBits = 0;
static unsigned char macroTapActive = 0;
static unsigned char macroTapType = 0;
static unsigned char macroTapValue = 0;

unsigned char macroPlayerIsRunning(void)
{
    return macroRunning;
}

unsigned char macroPlayerGetId(void)
{
    return macroSourceId;
}

unsigned char macroPlayerGetIndex(void)
{
    unsigned int total = macroActive.header.action_count;
    return macroIndex > total ? total : macroIndex;
}

unsigned char macroPlayerGetTotal(void)
{
    return macroActive.header.action_count;
}

unsigned int macroPlayerGetDelayMs(void)
{
    return macroDelayMs;
}

unsigned char macroPlayerGetMode(void)
{
    return macroActive.header.mode;
}

static void macroFileName(unsigned int id, char *out, size_t outLen)
{
    snprintf(out, outLen, MACRO_FILE_PREFIX "%u", id);
}

static void macroClearOutputs(void)
{
    memset(macroKeyboardBits, 0, sizeof(macroKeyboardBits));
    macroMediaBits = 0;
    macroMouseBits = 0;
    macroTapActive = 0;
    macroTapType = 0;
    macroTapValue = 0;
}

static int macroLoadOne(unsigned int id, macro_data_t *macro)
{
    char name[24] = {0};
    lfs_file_t file;
    lfs_t *fs = fsInit();
    macroFileName(id, name, sizeof(name));
    debugStage(1, 22);
    int err = lfs_file_open(fs, &file, name, LFS_O_RDONLY);
    if(err < 0)
    {
        debugEvent("macro_load_open_fail", err);
        return -1;
    }
    lfs_ssize_t len = lfs_file_read(fs, &file, macro, sizeof(*macro));
    lfs_file_close(fs, &file);
    if(len != sizeof(*macro)) debugEvent("macro_load_read_fail", (int)len);
    if(len != sizeof(*macro)) return -1;
    if(macro->header.magic != MACRO_MAGIC ||
       macro->header.version != MACRO_VERSION ||
       macro->header.id != id ||
       macro->header.action_count > MACRO_MAX_ACTIONS)
    {
        return -1;
    }
    return 0;
}

static int macroKeyboardBitIndex(unsigned char usage)
{
    if(usage >= 0xe0 && usage <= 0xe7) return usage - 0xe0;
    if(usage <= 0x77) return usage + 8;
    return -1;
}

static void macroSetKeyboardUsage(unsigned char usage, unsigned char down)
{
    int bit = macroKeyboardBitIndex(usage);
    if(bit < 0 || bit >= 128) return;
    if(down) macroKeyboardBits[bit / 8] |= (1u << (bit % 8));
    else macroKeyboardBits[bit / 8] &= ~(1u << (bit % 8));
}

static void macroSetMouseValue(unsigned char value, unsigned char down)
{
    unsigned int mask = 0;
    if(value < 3) mask = (1u << value);
    else mask = (value == 3) ? (1u << 24) : (0xffu << 24);
    if(down) macroMouseBits |= mask;
    else macroMouseBits &= ~mask;
}

static unsigned char macroUsageFromKeyValue(unsigned short keyValue)
{
    unsigned char value = keyValue & 0xff;
    if((keyValue >> 8) != 0) return 0xff;
    if(value >= 8) return value - 8;
    return 0xe0 + value;
}

static unsigned char macroLedByUsage(unsigned char usage)
{
    for(unsigned char x = 0; x < 5; x++)
    {
        for(unsigned char y = 0; y < 16; y++)
        {
            unsigned short keyValue = getKeymapByXY(x, y);
            if(macroUsageFromKeyValue(keyValue) == usage)
            {
                return macroLedByXY(x, y);
            }
        }
    }
    return 64;
}

static void macroShowKeyboardAction(unsigned char usage, unsigned char down)
{
    ws2812MacroPlayKey(macroLedByUsage(usage), down);
}
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

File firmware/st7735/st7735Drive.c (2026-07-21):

#include <stdio.h>
#include <stdlib.h>
#include <string.h>

#include "pico/stdlib.h"
#include "hardware/clocks.h"
#include "hardware/dma.h"
#include "hardware/spi.h"

#include "st7735Hw.h"

#define ST7735A   1
unsigned char st7735Reset(void)
{
    st7735RstCtrl(1); 
    sleep_ms(200);
    st7735RstCtrl(0); 
    sleep_ms(200);
    st7735RstCtrl(1); 
    sleep_ms(200);
    return 0;
}

void st7735SpiWritByte(unsigned char data)
{
    spi_write_blocking(spi0, &data, 1);
}

void st7735SpiWritNbyte(unsigned char pData[], unsigned int Len)
{
    spi_write_blocking(spi0, pData, Len);
}

static void ST7735SendCommand(unsigned char Reg)
{
    st7735DcCtrl(0);
    st7735SpiWritByte(Reg);
}

static void St7735SendData8Bit(unsigned char  Data)
{
    st7735DcCtrl(1);
    st7735SpiWritByte(Data);
}

void St7735SetWindows(unsigned short Xstart, unsigned short Ystart, unsigned short Xend, unsigned short Yend)
{
#if ST7735A == 0	
	Xstart = Xstart + 1;
	Xend = Xend + 1;
	Ystart = Ystart + 26;
	Yend = Yend+26;

#else

	Xstart = Xstart;
	Xend = Xend;
	Ystart = Ystart + 24;
	Yend = Yend+24;
#endif
	ST7735SendCommand(0x2a);
	St7735SendData8Bit(0);
	St7735SendData8Bit(Xstart);

	St7735SendData8Bit(0);
	St7735SendData8Bit(Xend);

	ST7735SendCommand(0x2b);
	St7735SendData8Bit(0);
	St7735SendData8Bit(Ystart);

    St7735SendData8Bit(0);
	St7735SendData8Bit(Yend);

	ST7735SendCommand(0x2C);
}

void st7735RegInit(void)
{
	st7735Reset();

    ST7735SendCommand(0X11);
    sleep_ms(120);
#if ST7735A == 0	
    ST7735SendCommand(0X21);
    ST7735SendCommand(0X21);
#endif
    ST7735SendCommand(0Xb1);
    St7735SendData8Bit(0x05);
    St7735SendData8Bit(0x3a);
    St7735SendData8Bit(0x3a);

    ST7735SendCommand(0Xb2);
    St7735SendData8Bit(0x05);
    St7735SendData8Bit(0x3a);
    St7735SendData8Bit(0x3a);

    ST7735SendCommand(0Xb3);
    St7735SendData8Bit(0x05);
    St7735SendData8Bit(0x3a);
    St7735SendData8Bit(0x3a);
    St7735SendData8Bit(0x05);
    St7735SendData8Bit(0x3a);
    St7735SendData8Bit(0x3a);

    ST7735SendCommand(0Xb4);
    St7735SendData8Bit(0x03);

	ST7735SendCommand(0xC0);
	St7735SendData8Bit(0x62);
	St7735SendData8Bit(0x02);
	St7735SendData8Bit(0x04);

    ST7735SendCommand(0xC1);
	St7735SendData8Bit(0xC0);

	ST7735SendCommand(0xC2);
	St7735SendData8Bit(0x0D);
	St7735SendData8Bit(0x00);

	ST7735SendCommand(0xC3);
	St7735SendData8Bit(0x8D);
	St7735SendData8Bit(0x6A);   

	ST7735SendCommand(0xC4);
	St7735SendData8Bit(0x8D); 
	St7735SendData8Bit(0xEE); 

	ST7735SendCommand(0xC5);  /*VCOM*/
	St7735SendData8Bit(0x0E);    

	ST7735SendCommand(0xE0);
	St7735SendData8Bit(0x10);
	St7735SendData8Bit(0x0E);
	St7735SendData8Bit(0x02);
	St7735SendData8Bit(0x03);
	St7735SendData8Bit(0x0E);
	St7735SendData8Bit(0x07);
	St7735SendData8Bit(0x02);
	St7735SendData8Bit(0x07);
	St7735SendData8Bit(0x0A);
	St7735SendData8Bit(0x12);
	St7735SendData8Bit(0x27);
	St7735SendData8Bit(0x37);
	St7735SendData8Bit(0x00);
	St7735SendData8Bit(0x0D);
	St7735SendData8Bit(0x0E);
	St7735SendData8Bit(0x10);

	ST7735SendCommand(0xE1);
	St7735SendData8Bit(0x10);
	St7735SendData8Bit(0x0E);
	St7735SendData8Bit(0x03);
	St7735SendData8Bit(0x03);
	St7735SendData8Bit(0x0F);
	St7735SendData8Bit(0x06);
	St7735SendData8Bit(0x02);
	St7735SendData8Bit(0x08);
	St7735SendData8Bit(0x0A);
	St7735SendData8Bit(0x13);
	St7735SendData8Bit(0x26);
	St7735SendData8Bit(0x36);
	St7735SendData8Bit(0x00);
	St7735SendData8Bit(0x0D);
	St7735SendData8Bit(0x0E);
	St7735SendData8Bit(0x10);

	ST7735SendCommand(0x3A); 
	St7735SendData8Bit(0x05);

	ST7735SendCommand(0x36);
	St7735SendData8Bit(0x68);
	ST7735SendCommand(0x29); 

}

//X 缓存
//Y 计数

/*
. SEND_DATA
// Y = 8				1
// 数据，侧载时钟		 2
// 时钟					3
//判断					4
JMP BACK			    5
*/

//程序1 

//设置CS DC												     5
//取32位到 OSR ，									    	  6

//最低8位复制到X  	//第一个像素的高8位先留着			  		7
// Y = 8													 4
//循环发送8位	 	//第一个像素的低8位先发出去			  		5 6 7 //还可以用Y计数			
//16位放ISR		   	//第二个像素低8位缓存起来，用ISR做缓存，	 8
//X 8位复制OSR	   	//把一个像素的高8位复制到OSR，				9
//循环发送8位	   	//发出去
//把ISR8位复制到OSR	//准备发第二个像素的低8位发出去
//循环发8位			//
//Y 8位复制到OSR	
//循环发8位			//

unsigned char st7735WindowUpdate(unsigned char x,unsigned char y,unsigned char x1,unsigned char y1,unsigned char *data, int *p)
{
	if(dma_channel_is_busy(getSpiDmaChan()) == true) return 0;
	St7735SetWindows(x, y, x1, y1);
	st7735DcCtrl(1);
	//spi_write_blocking(spi0, data, (width + 1) * (hight + 1) *2);
	//dma_channel_transfer_from_buffer_now(DMA_SPI_CHANNEL,data, (x1 - x + 1)* (y1 - y + 1 ) *2);
	spiSendDataDma(data,(x1 - x + 1)* (y1 - y + 1 ) *2,p);
	return 0;
}

unsigned char st7735DriveInit(void)
{
    st7735HwInit();
    st7735RegInit();

    return 0;
}

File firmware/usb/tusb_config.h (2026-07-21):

#pragma once

#include "../magic63_config.h"

// Windows only supports RNDIS, and apparently doesn't like composite devices with two configurations.
// Mac only supports CDC-ECM, which we present as the second config in a dual configuration device

// Linux supports either RNDIS, CDC-ECM or CDC-NCM

#define CFG_TUD_HID               4
#define CFG_TUD_ECM_RNDIS         1
#define CFG_TUD_CDC               MAGIC63_ENABLE_USB_CDC_DEBUG
#define CFG_TUD_MSC               0    // This enables mass storage
#define CFG_TUD_MSC_EP_BUFSIZE    512   // Also Add msc_disk.c and descritors
#define CFG_TUD_NCM               0

#define BOARD_DEVICE_RHPORT_NUM   0
#define BOARD_DEVICE_RHPORT_SPEED OPT_MODE_FULL_SPEED
#define CFG_TUSB_RHPORT0_MODE     (OPT_MODE_DEVICE | BOARD_DEVICE_RHPORT_SPEED)

#define CFG_TUD_CDC_RX_BUFSIZE   (64)
#define CFG_TUD_CDC_TX_BUFSIZE   (64)

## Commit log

2026-07-18 Add macro execution and device tooling
2026-07-21 Track project libraries
2026-07-21 Add key binding support for UI page jumps
    [hidKeyboard.c, pageChangeLogic.c]
2026-07-24 Prepare firmware project for release
    [上盖&定位板.step, 空格键帽.step, 键盘底盖V3.1.7.step]
2026-07-24 Use board unique ID for USB serial
2026-07-24 Update web and tools for P1 device address
2026-07-27 Derive RNDIS MAC from board ID
2026-07-27 Update case top cover STEP model
    [上盖&定位板.step]
2026-07-28 build: tighten firmware cmake dependencies
2026-07-28 Fix encoder key order in settings page
2026-07-30 Add MagicKey63 hardware design files
    [BOM_magicKey.xlsx]
2026-07-30 Use assigned Raspberry Pi USB VID PID
2026-07-30 Update 3D case files
    [空格键帽.step, 键盘底盖V3.1.7.step, 键盘底盖V3.1.8.step]
2026-07-31 Rename case 3D model files
    [keyboard-bottom-cover-v3.1.8.step, spacebar-keycap.step, spacebar-keycap.stl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]
2026-07-31 Add device discovery for Codex status tools
2026-08-01 docs: update hardware BOM
    [BOM_magicKey.xlsx]
